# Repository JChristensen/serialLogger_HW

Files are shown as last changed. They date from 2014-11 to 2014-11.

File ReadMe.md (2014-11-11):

# Serial Data Logger #

An Arduino-compatible logger that writes all serial data input on digital pin 0 (RXD) to a micro SD card. Firmware for the Serial Logger is at [https://github.com/JChristensen/serialLogger](https://github.com/JChristensen/serialLogger). A bill of materials is [available on Mouser.com](http://www.mouser.com/ProjectManager/ProjectDetail.aspx?AccessID=75ac867039).

The firmware can be programmed directly with an ICSP programmer or via a bootloader (use the standard Arduino Uno Optiboot bootloader). Before programming this board with an ICSP programmer, ensure that the SD card is removed.

The Serial Logger board can be powered in several ways:
- Via the FTDI header. This is handy if the MCU being logged uses 5V power.
- Via the power jack. Either 5V regulated or 7-12V can be connected to the jack. First ensure that the four-pin PWR SEL header is jumpered to match the input voltage.
- Via the four-pin PWR SEL header. Remove the jumper and connect either 5V regulated or 7-12V to the like-labeled pin. A ground pin is also provided on the PWR SEL header.

### Revision History ###

**16Oct2014 v2.0** -- Custom PC board, initial version.

### CC BY-SA ###
Serial Data Logger by Jack Christensen is licensed under CC BY-SA 4.0, http://creativecommons.org/licenses/by-sa/4.0/

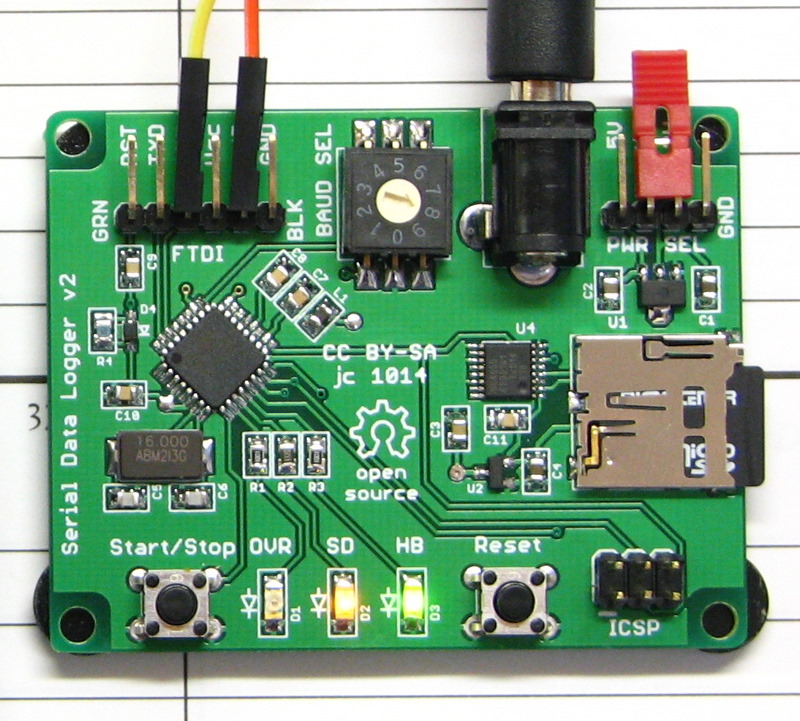
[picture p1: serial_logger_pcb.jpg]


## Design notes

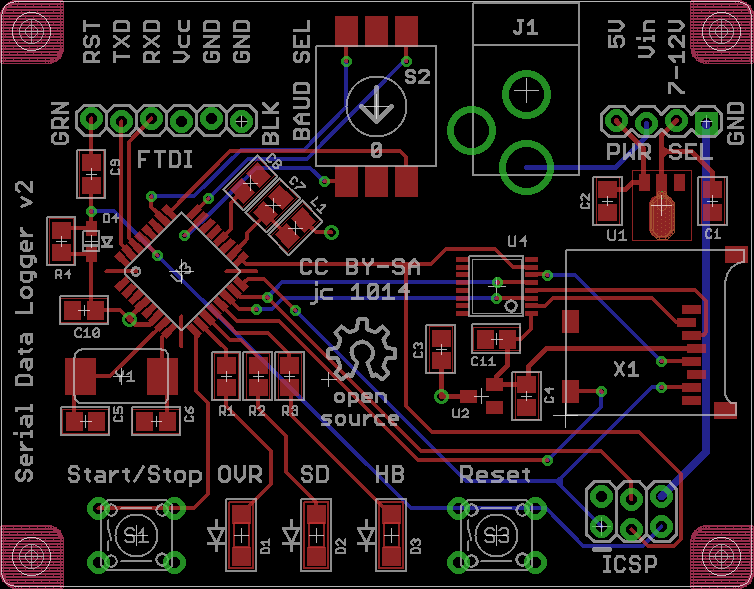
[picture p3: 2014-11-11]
board.png

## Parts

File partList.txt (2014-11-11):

Partlist

Exported from serialLogger.sch at 11/10/2014 7:54:04 PM

EAGLE Version 6.4.0 Copyright (c) 1988-2013 CadSoft

Assembly variant: 

Part     Value             Device                Package              Library  Sheet

C1       10uF              C-USM0805             M0805                _jc      1
C2       10uF              C-USM0805             M0805                _jc      1
C3       1uF               C-USM0805             M0805                _jc      1
C4       10uF              C-USM0805             M0805                _jc      1
C5       27pF              C-USM0805             M0805                _jc      1
C6       27pF              C-USM0805             M0805                _jc      1
C7       100nF             C-USM0805             M0805                _jc      1
C8       100nF             C-USM0805             M0805                _jc      1
C9       100nF             C-USM0805             M0805                _jc      1
C10      100nF             C-USM0805             M0805                _jc      1
C11      100nF             C-USM0805             M0805                _jc      1
D1       Bfr Overrun (RED) LEDCHIPLED_1206       CHIPLED_1206         _jc      1
D2       SD Activity (YEL) LEDCHIPLED_1206       CHIPLED_1206         _jc      1
D3       Heartbeat (GRN)   LEDCHIPLED_1206       CHIPLED_1206         _jc      1
D4       1N4148            DIODESOD-323F-A       SOD-323F-A           _jc      1
J1       Ext Pwr           POWER-JACK            KLDX-0202            _jc      1
JP1      FTDI              M06LOCK               1X06_LOCK            SparkFun 1
JP2      ICSP              AVR_SPI_PRG_62X3_LOCK 2X3_LOCK             _jc      1
JP3      Pwr Select        M04LOCK               1X04_LOCK            SparkFun 1
L1       10uH              INDUCTORM0805         M0805                _jc      1
R1       1K                R-US_M0805            M0805                _jc      1
R2       330               R-US_M0805            M0805                _jc      1
R3       1K                R-US_M0805            M0805                _jc      1
R4       10K               R-US_M0805            M0805                _jc      1
S1       Start/Stop        10-XXOCT              B3F-10XXOCT          _jc      1
S2       Baud Select       OMRON-A6RS-102        OMRON-A6RS-102       _jc      1
S3       RESET             10-XXOCT              B3F-10XXOCT          _jc      1
U1       MCP1702           MCP1700SOT89          SOT89                _jc      1
U2       MCP1700           MCP1700SOT23          SOT23                _jc      1
U3       ATmega328P-AU     MEGA8-AI              TQFP32-08            atmel    1
U4       74HC4050PW        4050PW                TSSOP16              40xx     1
X1       MICROSD           MICROSD               MICROSD              adafruit 1
Y1       16MHz             CRYSTALABM2           CRYSTAL-ABRACON-ABM2 _jc      1

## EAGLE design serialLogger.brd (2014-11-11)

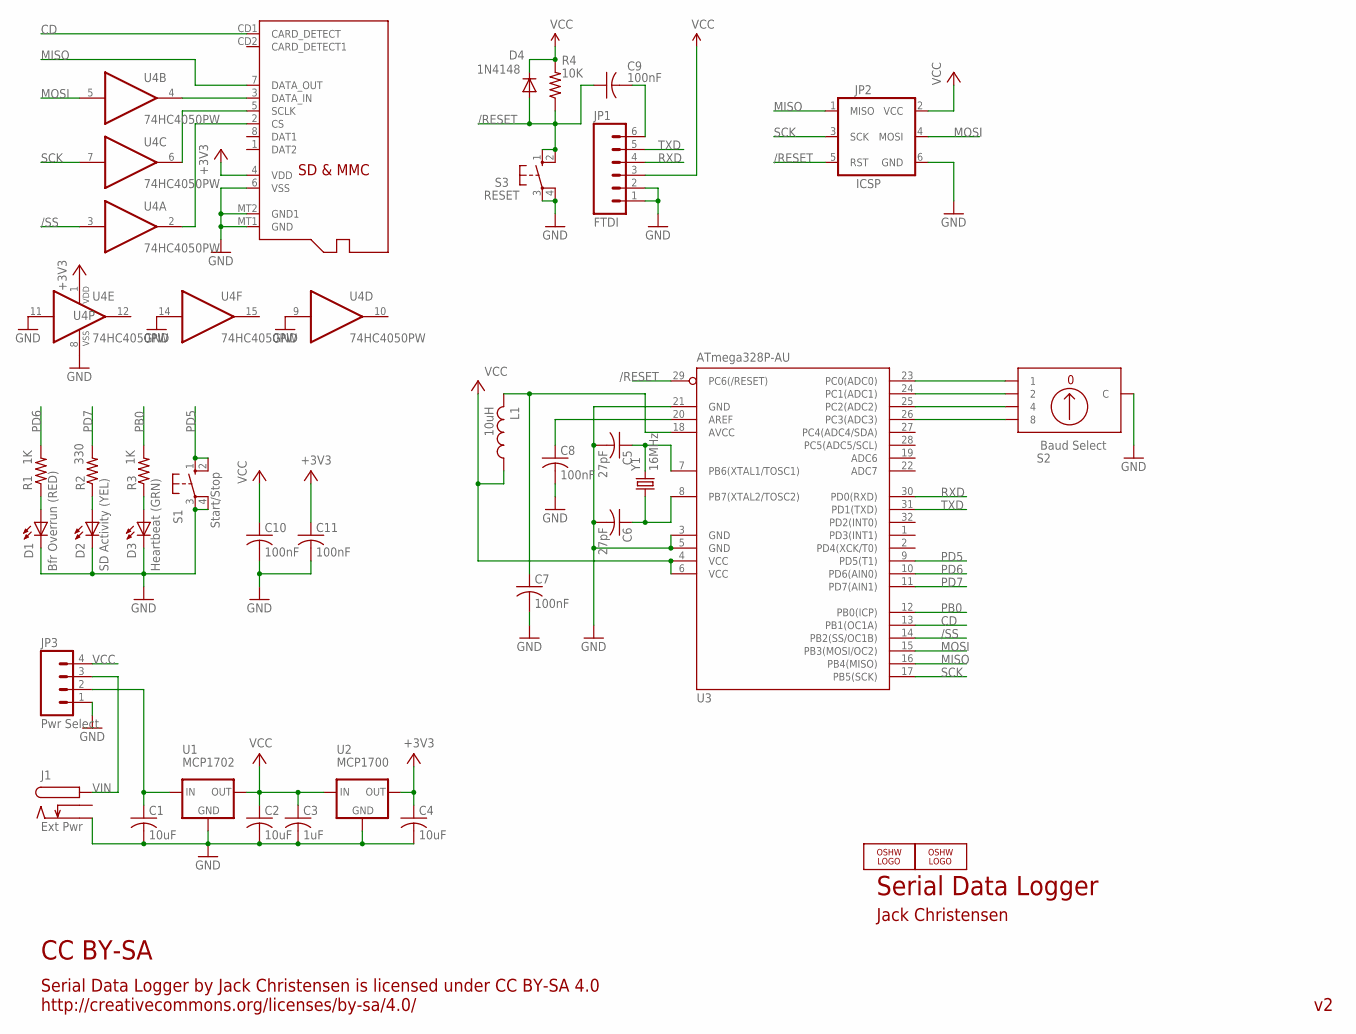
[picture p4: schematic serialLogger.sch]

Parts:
C1, C2, C4: 10uF; M0805
C3: 1uF; M0805
C5, C6: 27pF; M0805
C7, C8, C9, C10, C11: 100nF; M0805
D1: Bfr Overrun (RED); CHIPLED_1206
D2: SD Activity (YEL); CHIPLED_1206
D3: Heartbeat (GRN); CHIPLED_1206
D4: 1N4148; SOD-323F-A
J1: Ext Pwr; KLDX-0202
JP1: FTDI; 1X06_LOCK
JP2: ICSP; 2X3_LOCK
JP3: Pwr Select; 1X04_LOCK
L1: 10uH; M0805
LOGO1, LOGO2: OSHW_LOGO_10MILX0200-NT; OSHW_10X200_NOTEXT
R1, R3: 1K; M0805
R2: 330; M0805
R4: 10K; M0805
S1: Start/Stop; B3F-10XXOCT
S2: Baud Select; OMRON-A6RS-102
S3: RESET; B3F-10XXOCT
U1: MCP1702; SOT89
U2: MCP1700; SOT23
U3: ATmega328P-AU; TQFP32-08
U4: 74HC4050PW; TSSOP16
X1: MICROSD
Y1: 16MHz; CRYSTAL-ABRACON-ABM2

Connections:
+3V3: C4.1, C11.1, U2.2 (OUT), U4.1 (VDD), X1.4 (VDD)
/RESET: C9.1, D4.A, JP2.5 (RST), R4.1, S3.1 (S), S3.2 (S1), U3.29 (PC6(/RESET))
/SS: U3.14 (PB2(SS/OC1B)), U4.3 (I)
CD: U3.13 (PB1(OC1A)), X1.CD1 (CARD_DETECT)
GND: C1.2, C2.2, C3.2, C4.2, C5.2, C6.2, C7.2, C8.2, C10.2, C11.2, D1.C, D2.C, D3.C, J1.P$2, JP1.1, JP1.2, JP2.6 (GND), JP3.1, S1.3, S1.4 (P1), S2.C.1 (C), S2.C.2 (C), S3.3, S3.4 (P1), U1.1 (GND), U2.1 (GND), U3.3 (GND), U3.5 (GND), U3.21 (GND), U4.8 (VSS), U4.9 (I), U4.11 (I), U4.14 (I), X1.6 (VSS), X1.MT1 (GND), X1.MT2 (GND1)
MISO: JP2.1 (MISO), U3.16 (PB4(MISO)), X1.7 (DATA_OUT)
MOSI: JP2.4 (MOSI), U3.15 (PB3(MOSI/OC2)), U4.5 (I)
unnamed: D3.A, R3.1
unnamed: D2.A, R2.1
unnamed: D1.A, R1.1
unnamed: C1.1, JP3.2, U1.2 (IN), U1.2.1 (IN)
unnamed: S2.1, U3.23 (PC0(ADC0))
unnamed: S2.2, U3.24 (PC1(ADC1))
unnamed: S2.4, U3.25 (PC2(ADC2))
unnamed: S2.8, U3.26 (PC3(ADC3))
unnamed: U4.6 (O), X1.5 (SCLK)
unnamed: U4.2 (O), X1.2 (CS)
unnamed: U4.4 (O), X1.3 (DATA_IN)
unnamed: C5.1, U3.7 (PB6(XTAL1/TOSC1)), Y1.P$2 (2)
unnamed: C6.1, U3.8 (PB7(XTAL2/TOSC2)), Y1.P$1 (1)
unnamed: C8.1, U3.20 (AREF)
unnamed: C7.1, L1.2, U3.18 (AVCC)
PB0: R3.2, U3.12 (PB0(ICP))
PD5: S1.1 (S), S1.2 (S1), U3.9 (PD5(T1))
PD6: R1.2, U3.10 (PD6(AIN0))
PD7: R2.2, U3.11 (PD7(AIN1))
RST: C9.2, JP1.6
RXD: JP1.4, U3.30 (PD0(RXD))
SCK: JP2.3 (SCK), U3.17 (PB5(SCK)), U4.7 (I)
TXD: JP1.5, U3.31 (PD1(TXD))
VCC: C2.1, C3.1, C10.1, D4.K, JP1.3, JP2.2 (VCC), JP3.4, L1.1, R4.2, U1.3 (OUT), U2.3 (IN), U3.4 (VCC), U3.6 (VCC)
VIN: J1.P$1, JP3.3

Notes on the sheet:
Serial Data Logger
Jack Christensen
Serial Data Logger by Jack Christensen is licensed under CC BY-SA 4.0 http://creativecommons.org/licenses/by-sa/4.0/
CC BY-SA

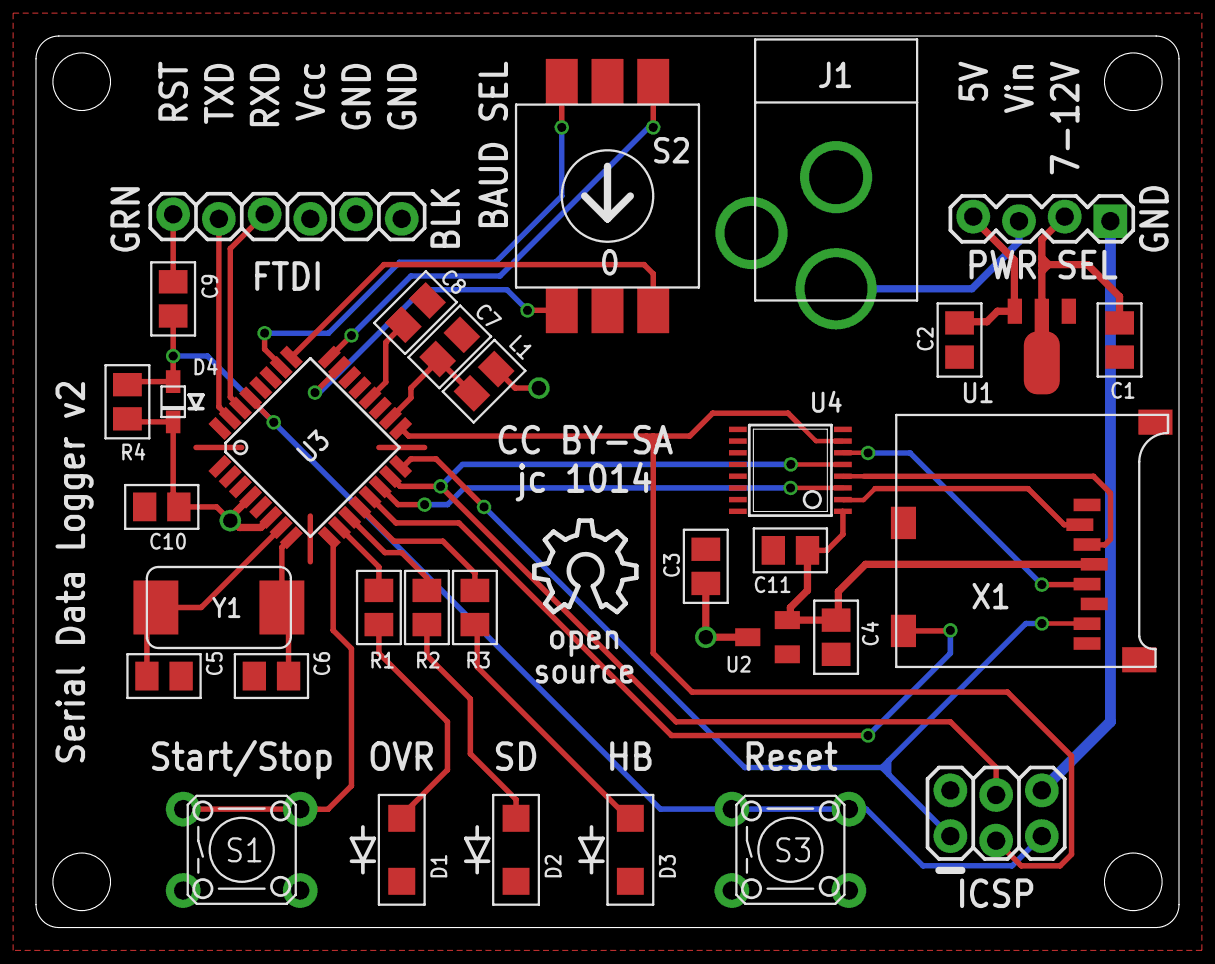
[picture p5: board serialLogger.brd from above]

Board: 2 copper layers, 63.5 x 49.5 mm, 35 parts (1 on the bottom side), 32 nets.

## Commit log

2014-10-08 Initial commit, breadboard version.
    [serialLogger.sch]
2014-10-11 Initial v2 board.
    [serialLogger.brd, serialLogger.sch]
2014-10-11 Change to Abracon xtal, refine board, add BOM spreadsheet.
    [bom.xlsx, serialLogger.brd, serialLogger.sch]
2014-11-11 Final v2 board
    [bom.xlsx, serialLogger.brd, serialLogger.sch]

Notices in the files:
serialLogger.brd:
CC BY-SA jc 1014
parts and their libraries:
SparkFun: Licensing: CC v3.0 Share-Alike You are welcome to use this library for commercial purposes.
